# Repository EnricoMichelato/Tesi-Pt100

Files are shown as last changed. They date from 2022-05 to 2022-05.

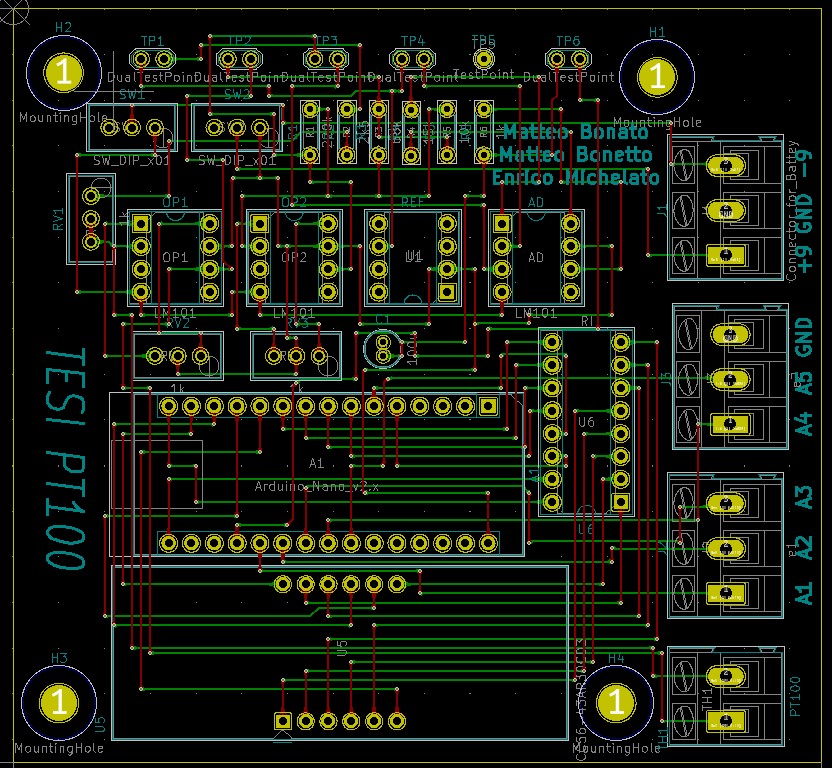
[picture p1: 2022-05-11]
PDF/Immagine_PCB.jpg

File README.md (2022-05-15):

# Tesi-Pt100
Tesi triennale in Ingegneria Industriale, Unitn.

Link utili:

https://www.miro.ing.unitn.it/compensazione-dinamica-di-un-sensore-di-temperaura-pt100/

https://www.youtube.com/watch?v=tVopkVoTj_M&ab_channel=EnricoMichelato

https://www.youtube.com/watch?v=0d6wAnDUfms&ab_channel=EnricoMichelato

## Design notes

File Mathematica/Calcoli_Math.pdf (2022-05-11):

# Calcoli per Ricavare Range di Temperature e sensibilità con il nosto range di temperature

## Dopo l’inseguitore di corrente il potenziale è (si consideri una corrente di 1 mA):

In[ ]:= V1 = -Rt 10⁻³;

## dopo l' amplificatore:

In[ ]:= V2 = - R2
R1

V1;

## conosciamo poi la seguente relazione R-T da datasheet:

In[ ]:= Rt = 100 1 + 0.0038501 T - 273.15;

## Ricavo poi la tensione in uscita dal secondo OP07CP:

In[ ]:= V2

Out[]=

R2 1 + 0.0038501 -273.15 + T

10 R1
sia Tmin la T minima leggibile, la differenza V2-Vref (con Vref=2.5 V in quanto è la tensione stabile a

## 2.5 del REF) sarà 0 in Tmin:

In[ ]:= Tminima = SolveV2 - 2.5 /. T → Tmin ⩵ 0, Tmin[[1]][[1]]

Out[]= Tmin →

2597.34 R1 2.5 + 0.00516548 R2

R1 |

R2

## Infine in uscita dall’opamp strumentale è valida la seguente relazione:

In[ ]:= V3 = G V2 - 2.5;

## e siccome la Tmax si raggiunge in corrispondenza dei 5V

In[ ]:= solG = Simplify[Solve[5 ⩵ V3 /. T → Tmax, G][[1]][[1]]]
Out[]= G → - | 2. R1
1. R1 + 0.00206619 R2 - 0.000154004 R2 Tmax
La resistenza da porre tra i pin 8 e 1 dell’OP07 vale (relazione ricavata dal datasheet del AD622ANZ):

In[ ]:= Rg = 50.5 × 10³

G - 1

/. solG

Out[]=

50 500.

-1 - | 2. R1
1. R1+0.00206619 R2-0.000154004 R2 Tmax

## Inoltre la sensibilità utilizzando arduino nano è pari a:

In[ ]:= sens = Tmax - Tmin

1023

;

## Ricavo Tmax [K], Tmin [K], sensibilità

Printed by Wolfram Mathematica Student Edition

In[ ]:= {Tmax, Tmin, s} = BlockR1 = 68 000 * 10 000 68 000 + 10 000

, R2 = 220 000, R18 = 15 000,

{
Tmax /. NSolve[Rg ⩵ R18, Tmax][[1]],
Tmin /. Tminima,
N[sens /. Tminima /. NSolve[Rg ⩵ R18, Tmax][[1]]] }

Out[]= {388.581, 270.728, 0.115203}

## Tmax [°C]

In[ ]:= Tmax - 273.15

Out[]= 115.431

## Tmin [°C]

In[ ]:= Tmin - 273.15

Out[]= -2.42176

# Range di voltaggi inserendo la temperatura della sonda: Procedura di Taratura dei trimmer

Ricavo la relazione T-V con V uscita in voltaggio dell’ultimo integrato prima di arrivare ad Arduino

## Nano, con il range di resistenze scelto:

In[ ]:= solt = CollectBlockR1 = 68 000 * 10 000 68 000 + 10 000, R2 = 220 000, R18 = 15 000, SolveV3 /. solG ⩵ V, T, V

Out[]= {{T → 270.728 + 23.5705 V}}

## E' NECESSARIO INSERIRE IL RELATIVO VALORE DI TEMPERATURA LA TARATURA (in[K]) :

Tset = 20 + 273.15
Girare il primo trimmer fino a quando l’uscita in tensione del primo opamp non risulta il valore

## seguente:

V1 /. R1 ->

68 000 * 10 000
68 000 + 10 000

/. R2 -> 220 000 /. R18 -> 15 000 /. T → Tset

Out[]= -0.1077
Girare il secondo trimmer fino a quando l’uscita in tensione del secondo opamp non risulta il valore

## seguente:

In[ ]:= V2 /. R1 ->

68 000 * 10 000
68 000 + 10 000

/. R2 -> 220 000 /. R18 -> 15 000 /. T → 20 + 273.15

Out[]= 2.71785

## Controllare come ulteriore prova di verifica la tensione in uscita da AD622ANZ:

### 2 Calcoli_Math.nb

In[ ]:= V3 /. solG /. R1 ->

68 000 * 10 000
68 000 + 10 000

/. R2 -> 220 000 /. R18 -> 15 000 /. T → 20 + 273.15

Out[]= 0.951262

Calcoli_Math.nb 3

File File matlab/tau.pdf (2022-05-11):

clear
close
clc

numProve=6;

for ii=1:numProve

dati=readmatrix(ii+".xlsx"); Tf(ii)=dati(end,2);
Ti(ii)=dati(1,2)+1;
Data{ii}=dati(:,2).*(dati(:,2)>dati(1,2)+1);

kk=1;
for jj=1:length(Data{ii})

if(Data{ii}(jj)~=0)
Data{ii}(kk)=Data{ii}(jj); kk = kk + 1;
end

end

end

Tc = 0.1;
tau=zeros(1,numProve);
min=zeros(1,numProve);

scelta=4;

%======= Costante di tempo per sistema primo ordine ==========

% Determino tau con 4 metodi differenti, poi ne faccio la media

% Determino tau col metodo grafico

%identifico il valore tra i dati aquisiti con minore differenza dal valore %atteso al tempo tau

for ii = 1:numProve
min(ii) = abs(Data{ii}(ii) -Tf(ii)-(Ti(ii) - Tf(ii))*0.368);
end

for ii = 1:numProve
for time = 1:length(Data{ii}(:,1))
if abs(Data{ii}(time,1) -Tf(ii)-(Ti(ii) - Tf(ii))*0.368)< min(ii) min(ii) = abs(Data{ii}(time) -Tf(ii)-(Ti(ii) - Tf(ii))*0.368); tau(ii) = time*Tc;
end
end
end

tau

tau = 1×6
93.2000 | 98.0000 | 94.5000 | 98.6000 | 98.0000 | 99.4000
Tau1 = mean(tau)

Tau1 = 96.9500

% Display del grafico
Ttau=zeros(1,numProve);
for ii = 1:numProve
Ttau(ii) = Tf(ii)+(Ti(ii) - Tf(ii))*0.368; end
Ttau

Ttau = 1×6
328.7213 330.0972 329.5921 333.1004 331.9012 330.1113

figure;
plot(Data{scelta});
hold on;
title("Prova "+scelta);
ylabel("T(°C)")
plot(ceil(tau(scelta)/Tc),Data{scelta}(ceil(tau(scelta)/Tc),1),'Color',[1 0 0],"MarkerSize",20,"Marker","o")

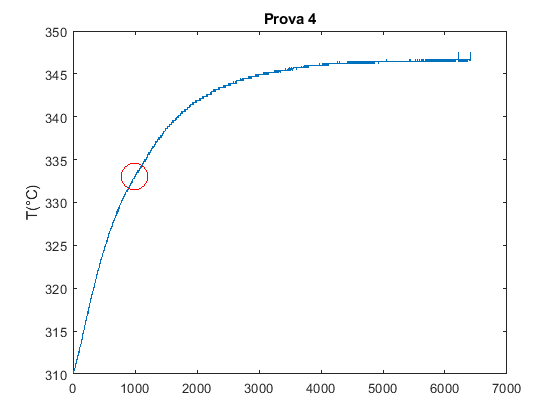
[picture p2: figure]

% secondo metodo
% linearizzo l'equazione e tramite il coefficiente valuto tau

a=zeros(2,numProve); %coefficienti
%filtro
[B,A]=butter(4,0.3,"low");
for ii=1:numProve
filtrato=filter(B,A,Data{ii});
X{ii}=(150:1000)*Tc;
Y{ii}=log((filtrato(150:1000)-Tf(ii))/(Ti(ii)-Tf(ii))); a(:,ii)=polyfit(X{ii},Y{ii},1);
tau(ii)=-1/a(1,ii);
end

figure;
plot(X{scelta},Y{scelta},'LineWidth',2); title("Prova "+ii);

hold on;
plot(X{ii},a(1,ii)*X{ii}+a(2,ii),'LineWidth',2); legend("dati","regressione lineare")

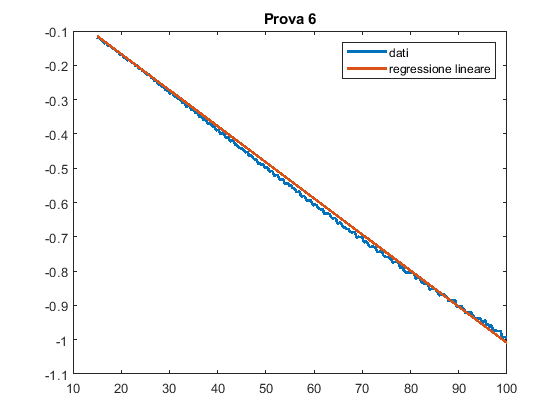
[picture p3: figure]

tau

tau = 1×6
89.6640 | 92.0419 | 88.6419 | 95.7775 | 91.6249 | 94.9989

Tau2=mean(tau)

Tau2 = 92.1248

%terzo metodo
tot=0;
for ii = 1:numProve
for time = 1:length(Data{ii}(:,1)) min(ii)=min(ii)+power(Data{ii}(time) ...
-Tf(ii)-(Ti(ii) - Tf(ii))*power(exp(1),-time*Tc/1),2); end
end

figure;

for ii = 1:numProve

if ii==scelta
hold on;
plot(Data{ii},'LineWidth',2); end

for tauVar=10:1:120

tot=0;
for time = 1:length(Data{ii}(:,1)) tot=tot+power(Data{ii}(time) ...
-Tf(ii)-(Ti(ii) - Tf(ii))*power(exp(1),-time*Tc/tauVar),2);

if ii==scelta
y(time)=Tf(ii)+(Ti(ii) ...
- Tf(ii))*power(exp(1),-time*Tc/tauVar); end

end

if mod(tauVar,10)==0 && ii==scelta hold on;
plot(y);
end

if tot< min(ii)
min(ii) = tot;
tau3(ii) = tauVar;
end

end

end

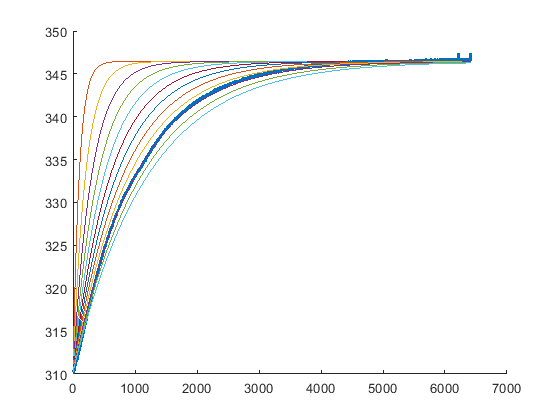
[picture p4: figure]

tau3

tau3 = 1×6
96 | 104 | 99 | 99 | 100 | 102
Tau3 = mean(tau3)

Tau3 = 100

%quarto metodo

for ii=1:numProve
for time=1:length(Data{ii})
tauVar2(time)=time*Tc/log( abs( (Ti(ii)-Tf(ii)) / (Data{ii}(time)-Tf(ii)) ) ); end
tau4(ii)=mean(tauVar2);
end

tau4

tau4 = 1×6
91.9827 114.5914 | 96.8996 | 80.0439 | 95.6320 | 92.7215
Tau4=mean(tau4)

Tau4 = 95.3119

%media delle medie

Tau1

Tau1 = 96.9500
Tau2

Tau2 = 92.1248
Tau3

Tau3 = 100
Tau4

Tau4 = 95.3119

TAUtot=(Tau1+Tau2+Tau3+Tau4)/4

TAUtot = 96.0967

t7=0:127

t7 = 1×128
0 | 1 | 2 | 3 | 4 | 5 | 6 | 7 | 8 | 9 | 10 | 11 | 12
y=sin(0.15*t7)

y = 1×128
0 | 0.1494 | 0.2955 | 0.4350 | 0.5646 | 0.6816 | 0.7833 | 0.8674
plot(t7,y)

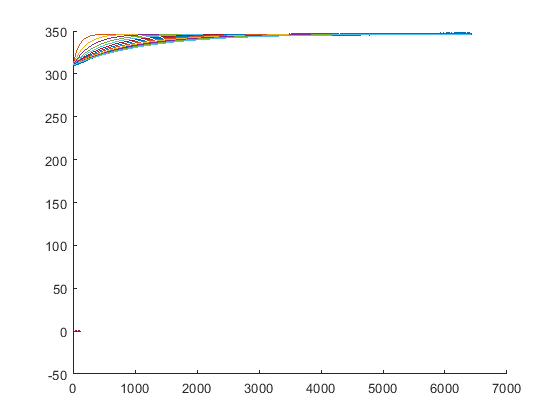
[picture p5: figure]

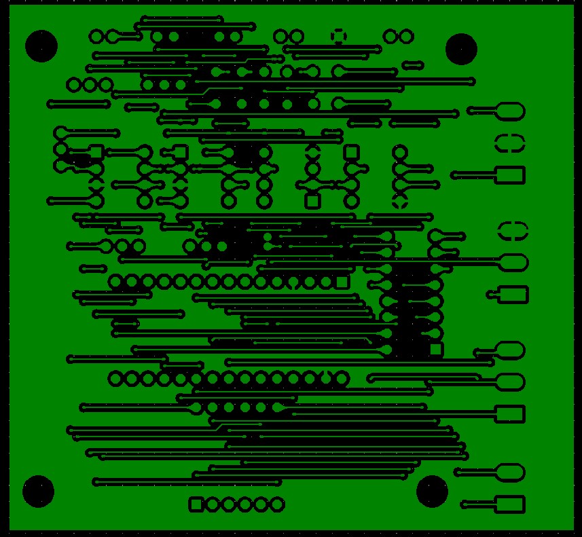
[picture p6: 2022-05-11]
Immagine file gerber/B_Cu.jpg

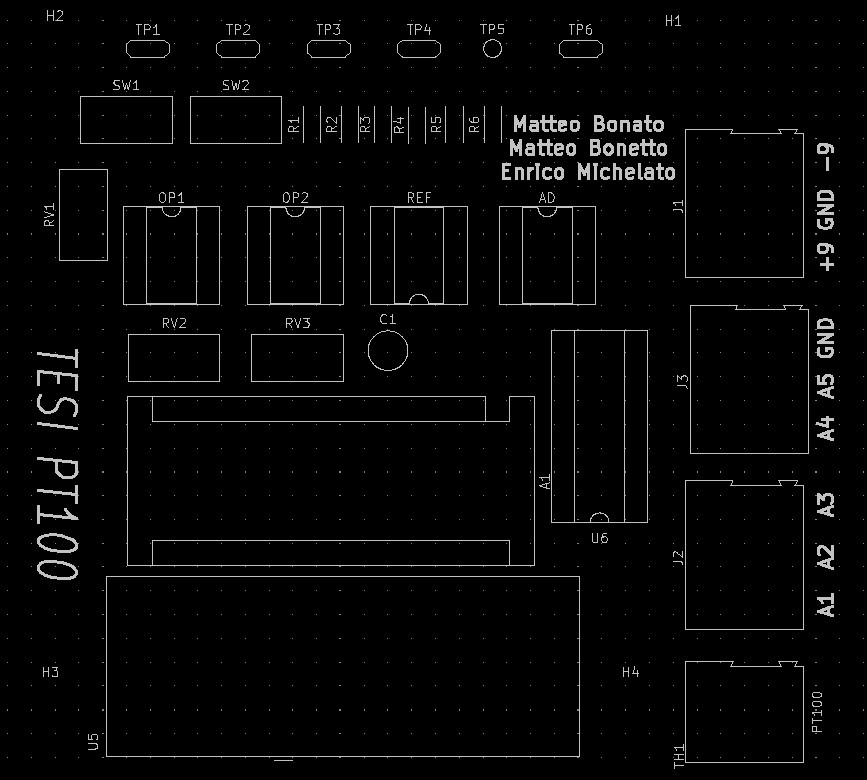
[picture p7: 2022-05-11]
Immagine file gerber/F_SilkS.jpg

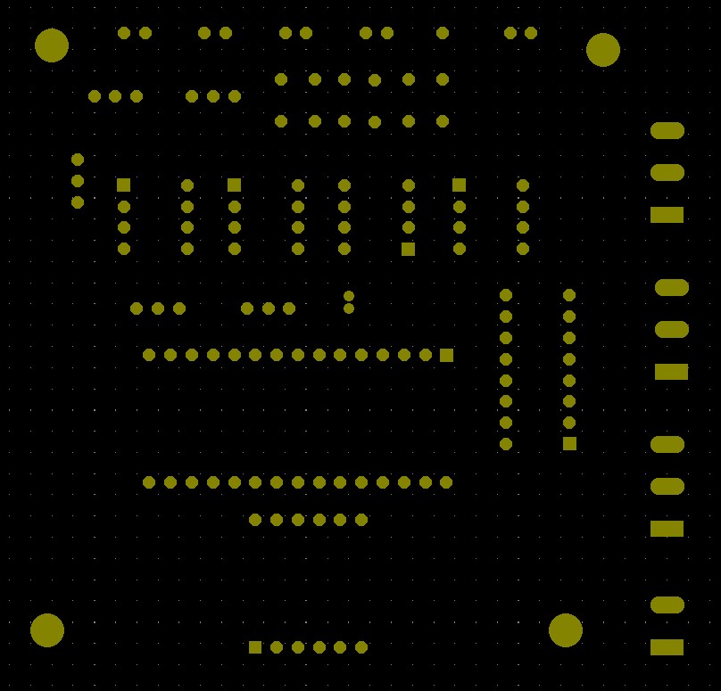
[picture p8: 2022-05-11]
Immagine file gerber/F_Mask.jpg

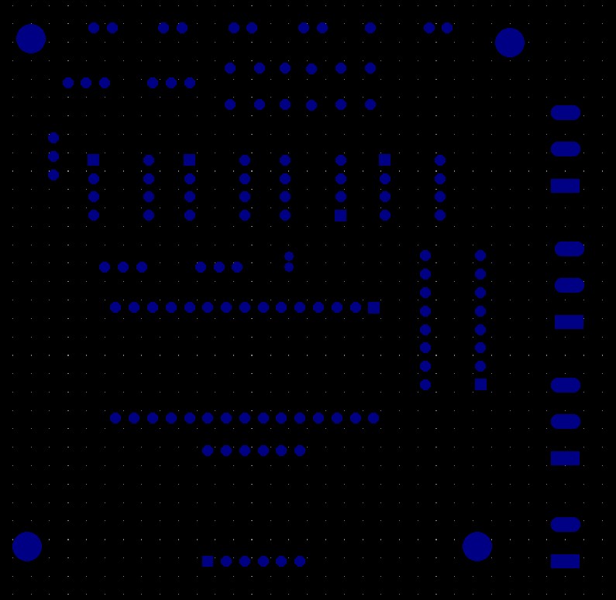
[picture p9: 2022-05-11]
Immagine file gerber/B_Mask.jpg

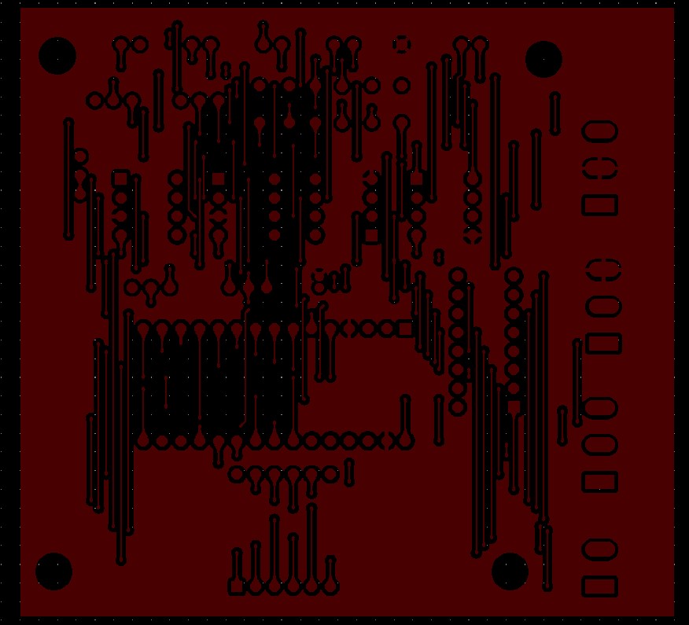
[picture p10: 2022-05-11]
Immagine file gerber/F_Cu.jpg

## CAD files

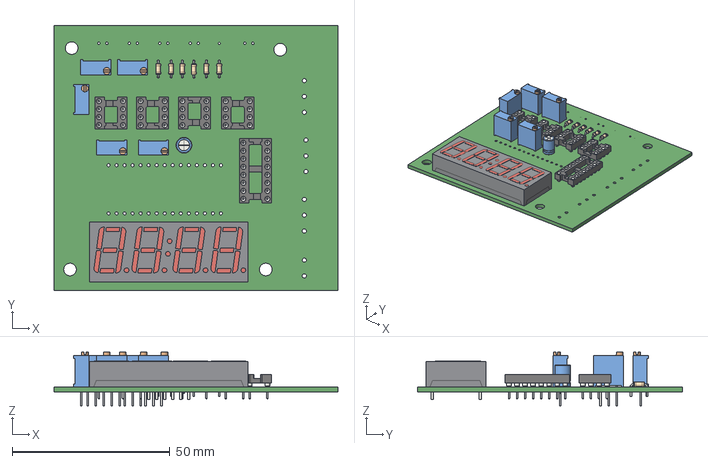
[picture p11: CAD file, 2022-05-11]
File_3D/PCB_Definitivo.step
89.9 x 83.8 x 17.1 mm

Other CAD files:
Custodia/Assieme1.iam
Custodia/PCB_Definitivo.iam
Custodia/Parte1.ipt

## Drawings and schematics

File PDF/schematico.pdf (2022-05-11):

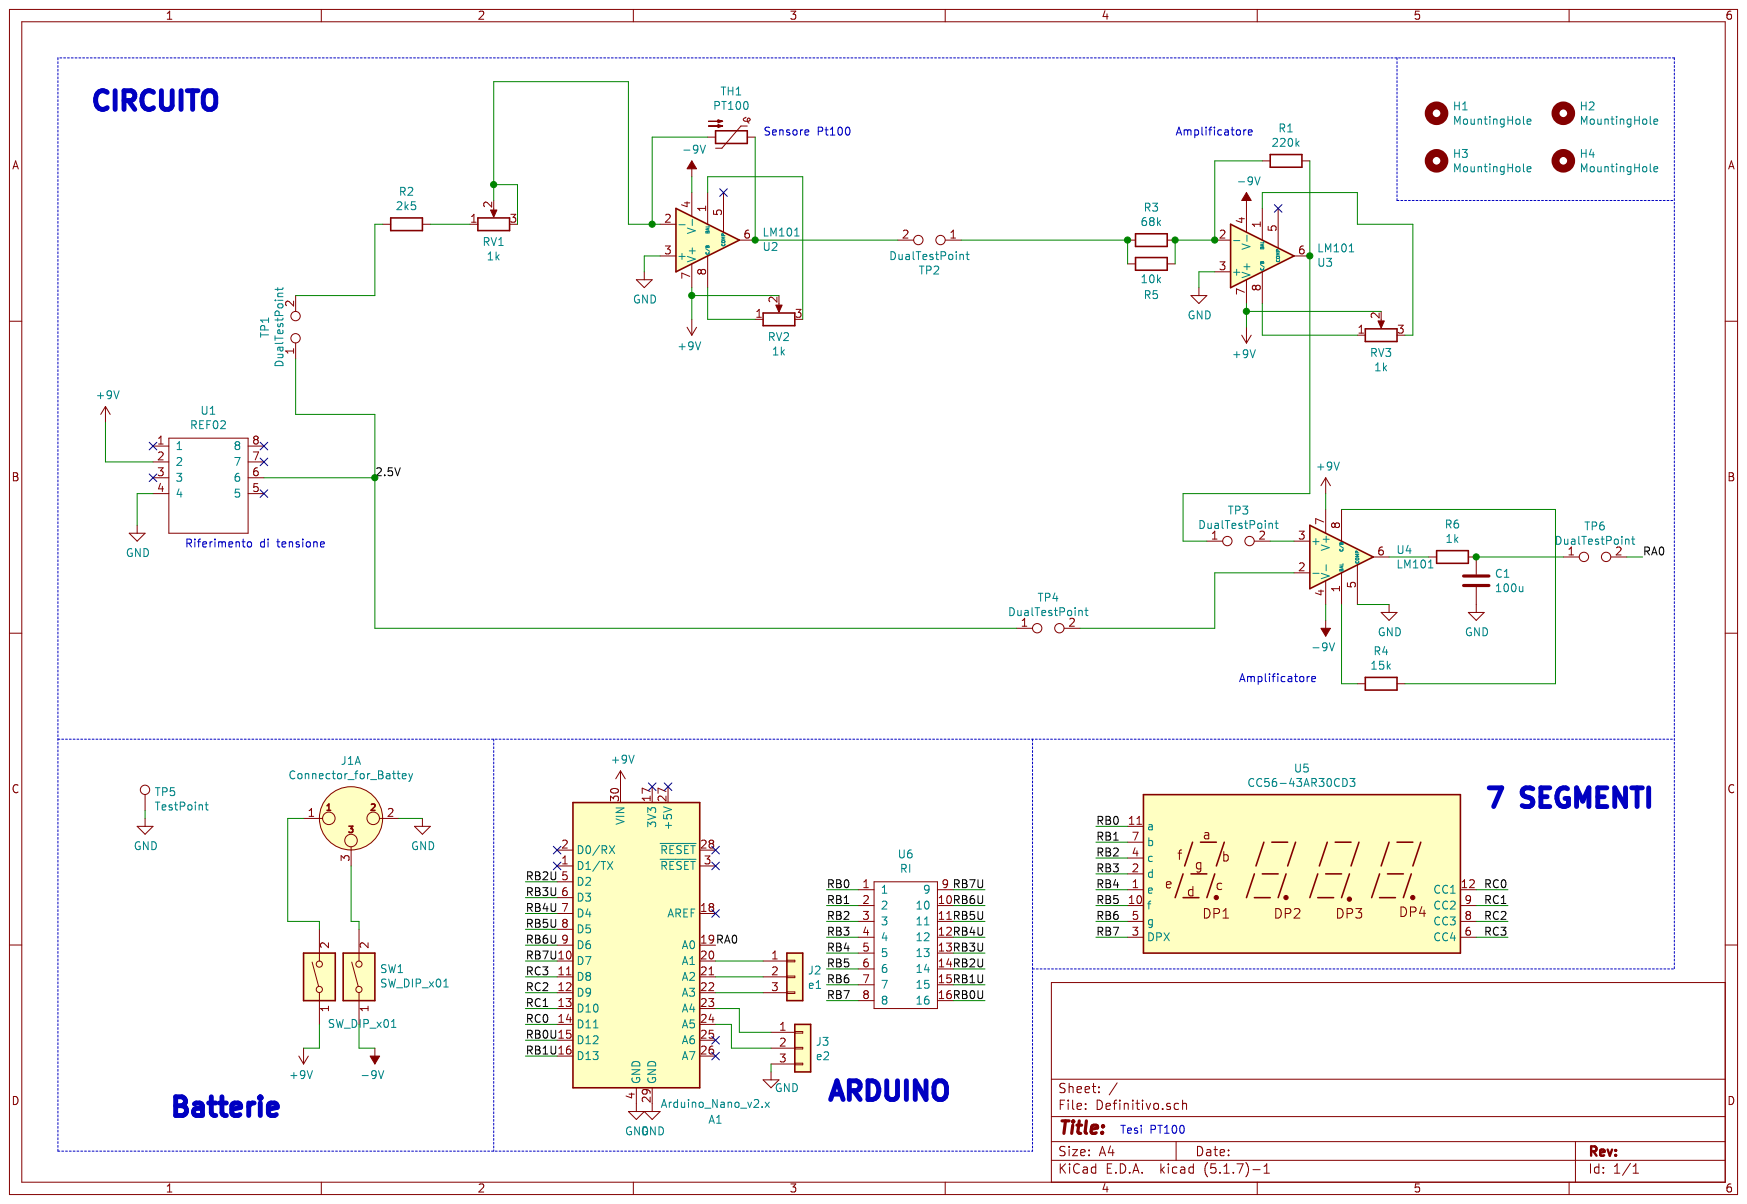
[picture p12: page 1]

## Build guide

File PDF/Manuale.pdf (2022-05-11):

Universita degli Studi di Trento `

Dipartimento di Ingegneria Industriale

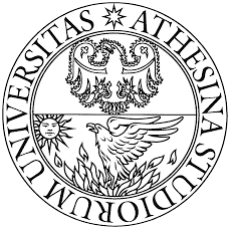
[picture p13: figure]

TESI: COMPENSAZIONE DINAMICA DI UN SENSORE DI TEMPERATURA PT100

Prodotto da
Matteo Bonato, Matteo Bonetto, Enrico Michelato

Anno Accademico 2021-2022

## Sommario

1 Circuito | 2
2 Assemblaggio | 4
3 Configurazioni iniziali | 5
4 Ulteriori utilizzi del circuito | 7

# 1 Circuito

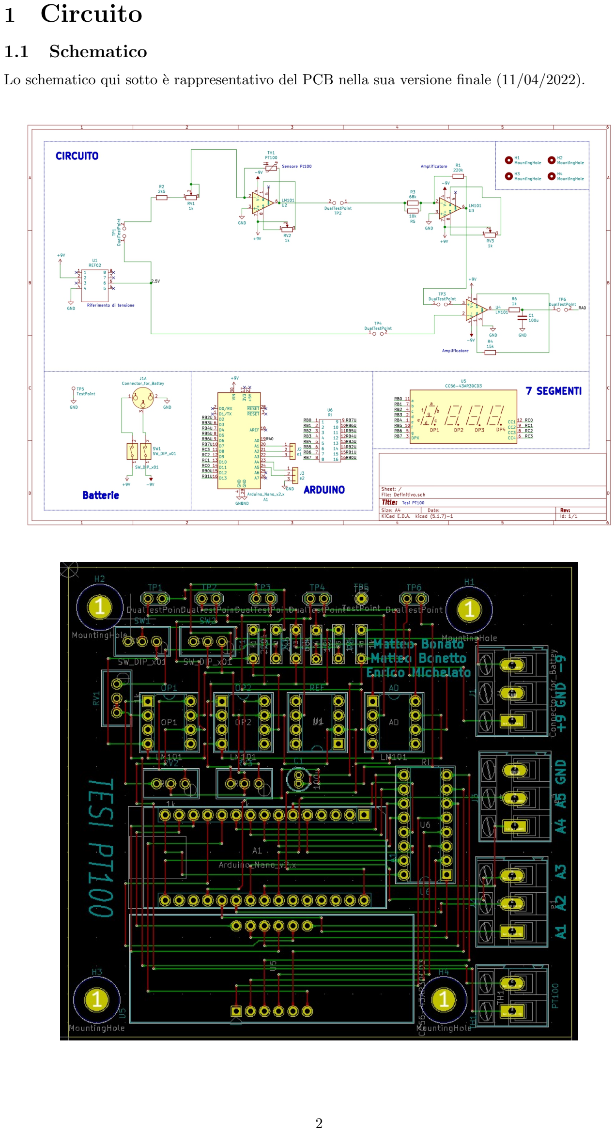
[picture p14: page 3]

### 1.1 Schematico

Lo schematico qui sotto `e rappresentativo del PCB nella sua versione finale (11/04/2022).

### 1.2 PCB

Quella che segue `e una foto del PCB gi`a assemblato.

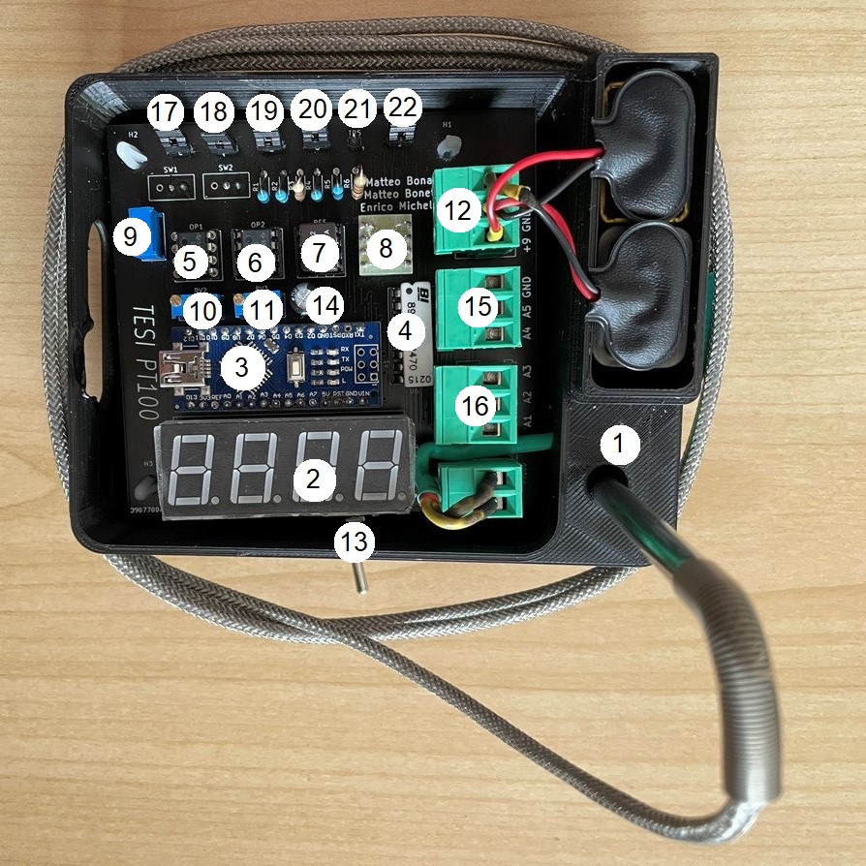
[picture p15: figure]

I componenti numerati sono i seguenti:

1. Sonda Pt100
2. Display 7 segmenti
3. Arduino NANO
4. Array di resistenze (per display 7 segmenti)
5. OP1 (1° opamp, U2)
6. OP2 (2° opamp, U3)
7. REF (Regolatore di tensione, U3)
8. AD (Amplificatore per strumentazione, U4)
9. Trimmer 1 (controllo corrente OP1)
10. Trimmer 2 (controllo guadagno OP1)
11. Trimmer 3 (controllo guadagno OP2)
12. Alimentazione (+9 V, GND, -9 V)
13. Switch alimentazione

14. Condensatore 100 uF
15. Entrate analogiche (A4, A5, GND)
16. Entrate analogiche (A1, A2, A3)
17. TP1 (per leggere corrente su OP1)
18. TP2 (per leggere tensione in uscita da OP1)
19. TP3 (per leggere tensione in uscita da OP2)
20. TP4 (per leggere tensione in uscita da REF)
21. TP5 (GND)
22. TP6 (collegato ad Arduino)

Tutti i componenti non presenti in questa lista sono comunque presenti sullo schematico.

# 2 Assemblaggio

In questa sezione viene spiegato come assemblare il circuito. E’ necessario l’utilizzo di un multimetro (voltmetro e amperometro). La maggior parte dei componenti risulter`a gi`a assemblata. Qui sotto una foto utile per il corretto orientamento dei componenti.

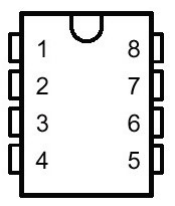
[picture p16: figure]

1. Inserire la sonda PT100 (1), un cavo in ogni slot. Se la Pt100 `e a 3 fili, i due fili dello stesso colore (di solito rosso) vanno uniti come se fossero uno solo
2. Inserire l’alimentazione (12): 2 batterie da 9V cariche (almeno 8V, controllarle con voltmetro prima di utilizzarle), che hanno il GND in comune. Verificarne la corretta disposizione
3. Inserire un OP07CP in OP1 (5)
4. Inserire un OP07CP in OP2 (6)
5. Inserire un REF43GZ in REF (7)
6. Inserire un AD622 in AD (8)
7. Assicurarsi che tutti i cappucci dei test point (TP1, TP2...) siano inseriti correttamente. Cambiarli se laschi
8. Ora si pu`o inserire Arduino e collegarlo al PC

E’ altamente consigliabile inserire Arduino solo dopo aver effettuato gli accertamenti sull’alimentazione. Se l’alimentazione dovesse essere errata, Arduino potrebbe danneggiarsi.

# 3 Configurazioni iniziali

### 3.1 Misure circuitali

Prima di iniziare ad utilizzare il circuito `e necessario verificare che tutti i componenti funzionino adeguatamente. Eseguire i passaggi sottostanti in ordine.

1. Aprire il file MATLAB taratura.mlx. Assegnare alla variabile temperatura la temperatura della Pt100 (guardare il termostato della stanza). Il codice calcoler`a le variabili vOP1, vOP2 e vAD, necessarie in seguito
2. Accendere gli switch dell’alimentazione (13).
3. Misurare la tensione dal REF (7), tramite il pin sinistro di TP4 (20): deve essere pari a 2,5V. Rimettere poi il cappuccio a TP4 (20)
4. Togliere il cappuccio a TP1 (17). Misurare la corrente ai suoi capi. Regolare il Trimmer 1
(9) fino a quando non passa esattamente 1 mA. Rimettere il cappuccio a TP1 (17)
5. Misurare la tensione in uscita da OP1 (5) tramite il pin destro di TP2 (18). Regolare il trimmer 2 (10) fino a quando la tensione misurata `e esattamente pari a vOP1. Rimettere poi il cappuccio a TP2 (18)
6. Misurare la tensione in uscita da OP2 (6) tramite il pin sinistro di TP3 (19). Regolare il trimmer 3 (11) fino a quando la tensione misurata `e esattamente vOP2. Rimettere poi il cappuccio a TP3 (19)
7. Misurare la tensione in uscita da AD (8) tramite il pin sinistro di TP6 (22). La tensione deve essere pari a vAD. Rimettere poi il cappuccio a TP6 (22)

### 3.2 Configurazione PC

Di seguito i passaggi da effettuare per utilizzare correttamente il codice MATLAB.

1. Se l’Arduino NANO utilizzato non `e della marca ufficiale Arduino, ma della marca ELEGOO, e se il sistema operativo del PC `e Windows, `e necessario scaricare questo driver per la corretta compatibilit`a: DriverELEGOO (https://www.elegoo.com/blogs/arduino-projects/elegoo-arduino-nano-board-ch340-usb-driver)
2. Ora bisogna trovare la porta del PC a cui `e collegato Arduino
- Trovare la porta su Windows

– Aprire Gestione dispositivi, ed espandere la lista Porte (COM e LPT)

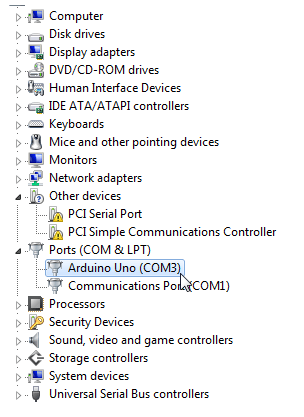
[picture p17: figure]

– La porta a cui `e collegato Arduino `e, per esempio, ”COM3”
- Trovare la porta su Macintosh

– Aprire il terminale e digitare: ls /dev/*
– La porta apparir`a nel formato /dev/tty.usbmodem* o /dev/tty.usbserial* , con * numero della porta
- Trovare la porta su Linux

– Aprire il terminale e digitare: ls /dev/tty*
– La porta apparir`a nel formato /dev/ttyUSB* o /dev/ttyACM* , con * numero della porta
3. Aprire il file MATLAB TESIPt100.mlx. Sostituire la stringa porta a riga 6 con la porta rilevata sul vostro PC
- Esempio su Windows
- Esempio su Mac/Linux

Il codice `e ora funzionante e pu`o essere utilizzato.

# 4 Ulteriori utilizzi del circuito

### 4.1 Utilizzo degli ingressi analogici di Arduino

Sul circuito sono stati predisposti degli slot per la lettura di segnali tramite dei pin analogici di Arduino (15, 16).
E’ importante ricordarsi che l’entrata analogica 1 (15) `e collegata rispettivamente ai pin A4, A5 e GND di Arduino.
L’entrata analogica 2 (16) `e collegata rispettivamente ai pin A1, A2 e A3 di Arduino.
Per campionare un segnale con questa modalit`a `e necessario innanzitutto aprire il file MATLAB campionatura.mlx.
Impostare la corretta porta seriale, come spiegato al relativo paragrafo (3.2)
Prima di iniziare a campionare `e necessario tuttavia impostare il corretto pin utilizzato, cambiando la variabile pinAnalog a riga 8.

### 4.2 Lettura Voltaggio in uscita su TP6

Il voltaggio in uscita dall’AD622 (8) viene letto dal pin analogico A0 di Arduino. Prima che questo segnale arrivi ad Arduino `e possibile interromperlo tramite TP6 (22).
Il segnale pu`o quindi essere prelevato da un capo di TP6 (22) per molteplici scopi.
Pu`o essere dato come input ad un circuito derivatore (opamp per derivazione), o possono essere applicati su di esso dei filtri.
Il segnale pu`o quindi essere riportato, per esempio, all’altro capo di TP6 (22), per essere letto dal pin analogico A0 di Arduino, oppure sulle altre uscite analogiche (15, 16) descritte al punto precedente (4.1).

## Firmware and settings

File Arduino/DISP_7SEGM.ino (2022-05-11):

int collegamenti[]={11,10,9,8},j=0;
float temp;
bool numeri[10][8]={{1,1,1,1,1,1,0,0},{0,1,1,0,0,0,0,0},{1,1,0,1,1,0,1,0},{1,1,1,1,0,0,1,0},{0,1,1,0,0,1,1,0},{1,0,1,1,0,1,1,0},{1,0,1,1,1,1,1,0},{1,1,1,0,0,0,0,0},{1,1,1,1,1,1,1,0},{1,1,1,1,0,1,1,0}};


void setup() {
  byte digitPins[] = {11,10,9,8,7,6,5,4,3,2,13,12};
  byte AnalogPins[]={A0};
  pinMode(11,OUTPUT);
  pinMode(10,OUTPUT);
  pinMode(9,OUTPUT);
  pinMode(8,OUTPUT);
  pinMode(7,OUTPUT);
  pinMode(6,OUTPUT);
  pinMode(5,OUTPUT);
  pinMode(4,OUTPUT);
  pinMode(3,OUTPUT);
  pinMode(2,OUTPUT);
  pinMode(12,OUTPUT);
  pinMode(13,OUTPUT);
  pinMode(A0,INPUT);
  //Serial.begin(9600);
}


void mostra_display(bool numero[]){
  int ii;
  ii=0;
  
  if(numero[ii]==true)
      digitalWrite(12,HIGH);
  else
      digitalWrite(12,LOW);
      
  ii=1;
  
  if(numero[ii]==true)
      digitalWrite(13,HIGH);
    else
      digitalWrite(13,LOW);

  ii=2;
  
  do{
    if(numero[ii]==true)
      digitalWrite(ii,HIGH);
    else
      digitalWrite(ii,LOW);
    ii++;
  }while(ii<=7);
}


void accendi(int digit){
  int ii;
  for(ii=3;ii>=0;ii--){
    if(ii!=digit)
      digitalWrite(collegamenti[ii],HIGH);
    else
      digitalWrite(collegamenti[ii],LOW);
  }
}


void mostra_numero(float num,int attesa){
  int numint=num*10;
  accendi(5);
  
  accendi(3);
  mostra_display(numeri[numint%10]);
  delay(attesa);
  accendi(2);
  mostra_display(numeri[(numint/10)%10]);
  digitalWrite(7,HIGH);
  delay(attesa);
  accendi(1);
  mostra_display(numeri[(numint/100)%10]);
  delay(attesa);
  accendi(0);
  mostra_display(numeri[(numint/1000)%10]);
  delay(attesa); 

  accendi(5);
}


void loop() {
  temp=-9.97377*(-27.3868 - (analogRead(A0)*5.000/1023.000))-273.15+3;
  //Serial.println(-9.97377*(-27.3868 - (analogRead(A0)*5.0/1023.0))-273.15);
  while(j<100){
    mostra_numero(temp,5);
    j++;
  }
  j=0;
   
}
